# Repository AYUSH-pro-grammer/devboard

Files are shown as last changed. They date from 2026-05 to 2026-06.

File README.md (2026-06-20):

# DevBoard

Custom RP2040-based development board for embedded systems and hardware prototyping.

## Images

### Front
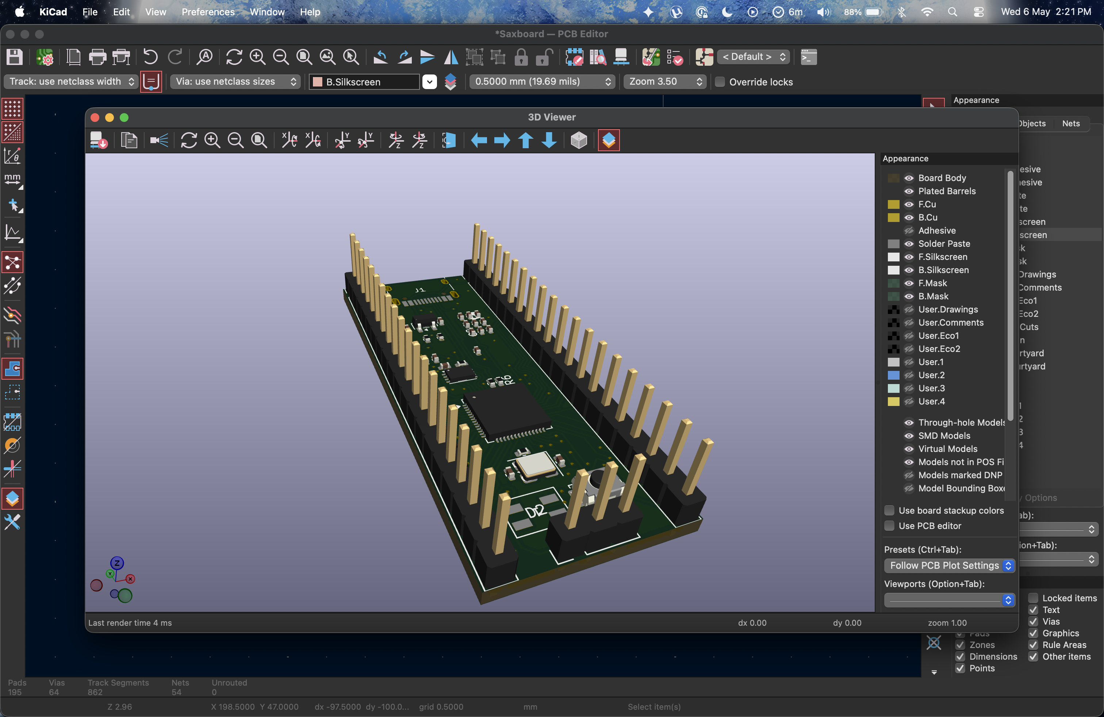
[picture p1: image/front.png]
Front

Screenshot 2026-06-02 at 10 48 57 AM

### Back
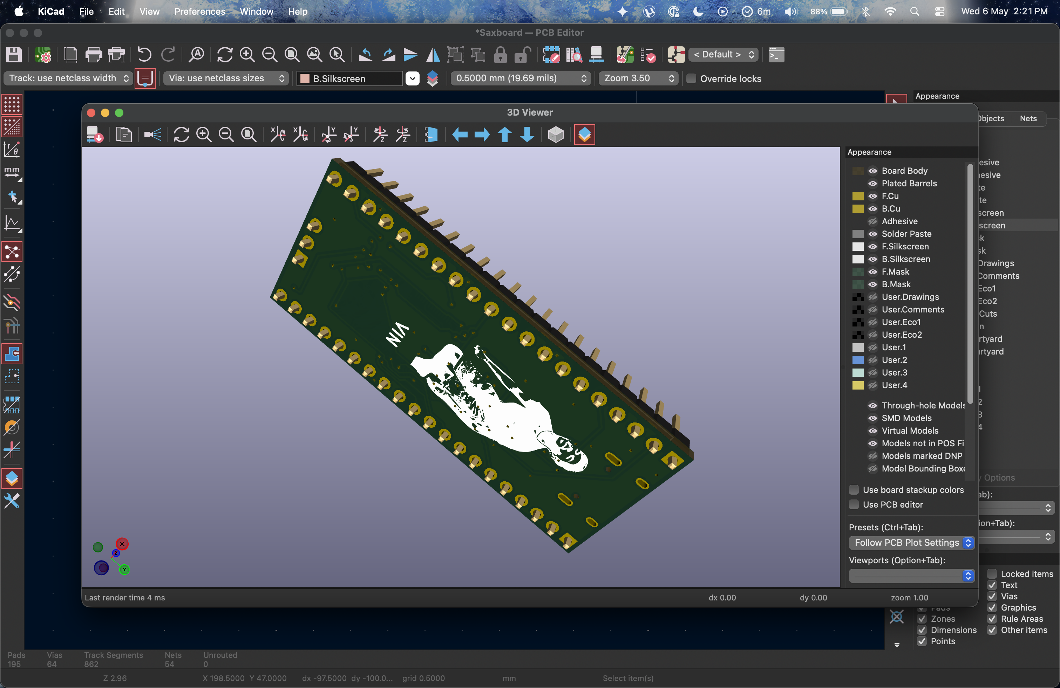
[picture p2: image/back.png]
Back


### PCB
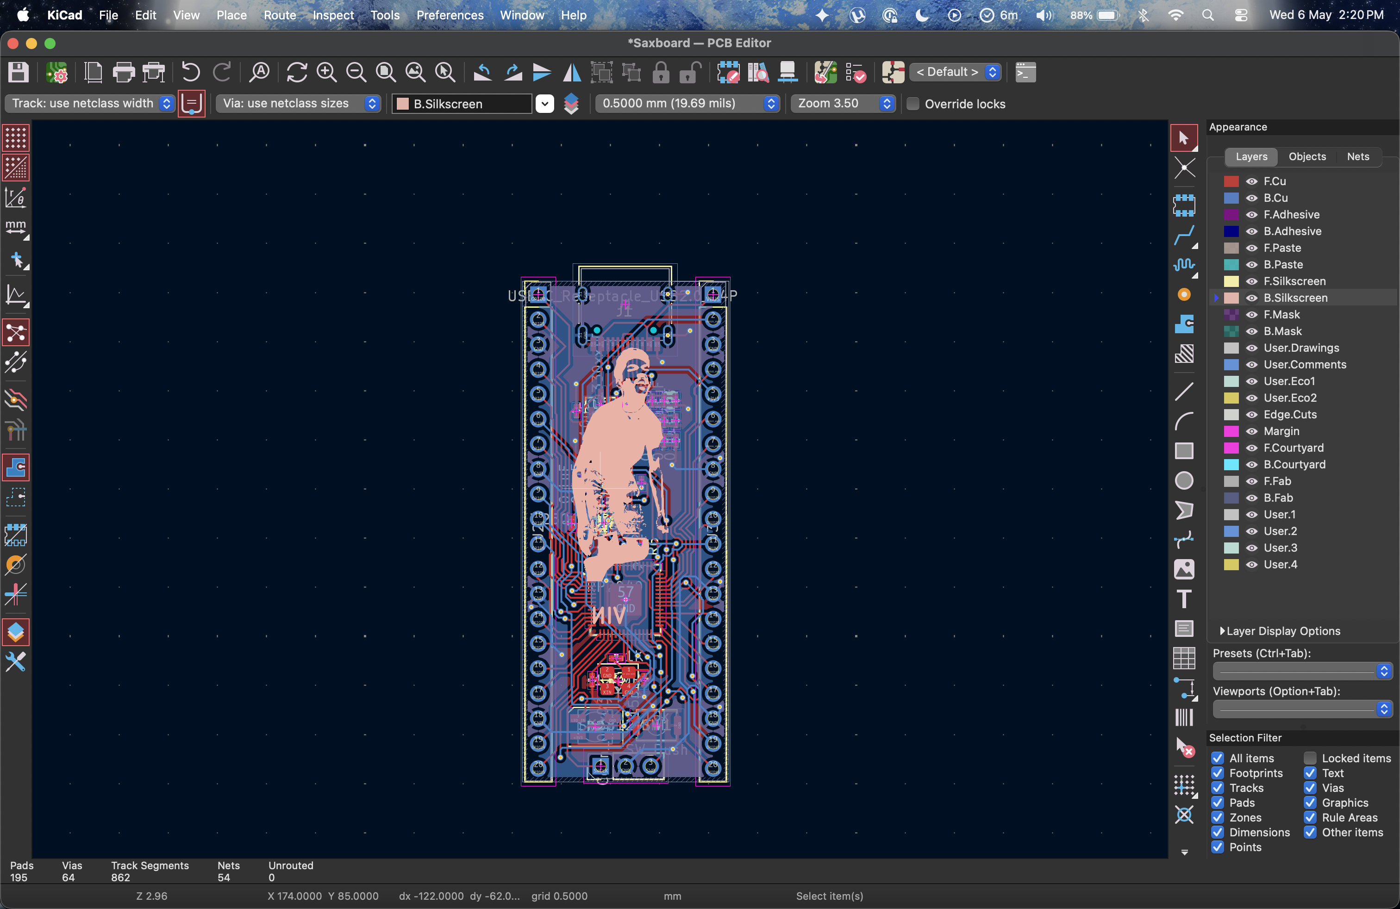
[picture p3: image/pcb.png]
PCB


### Schematic
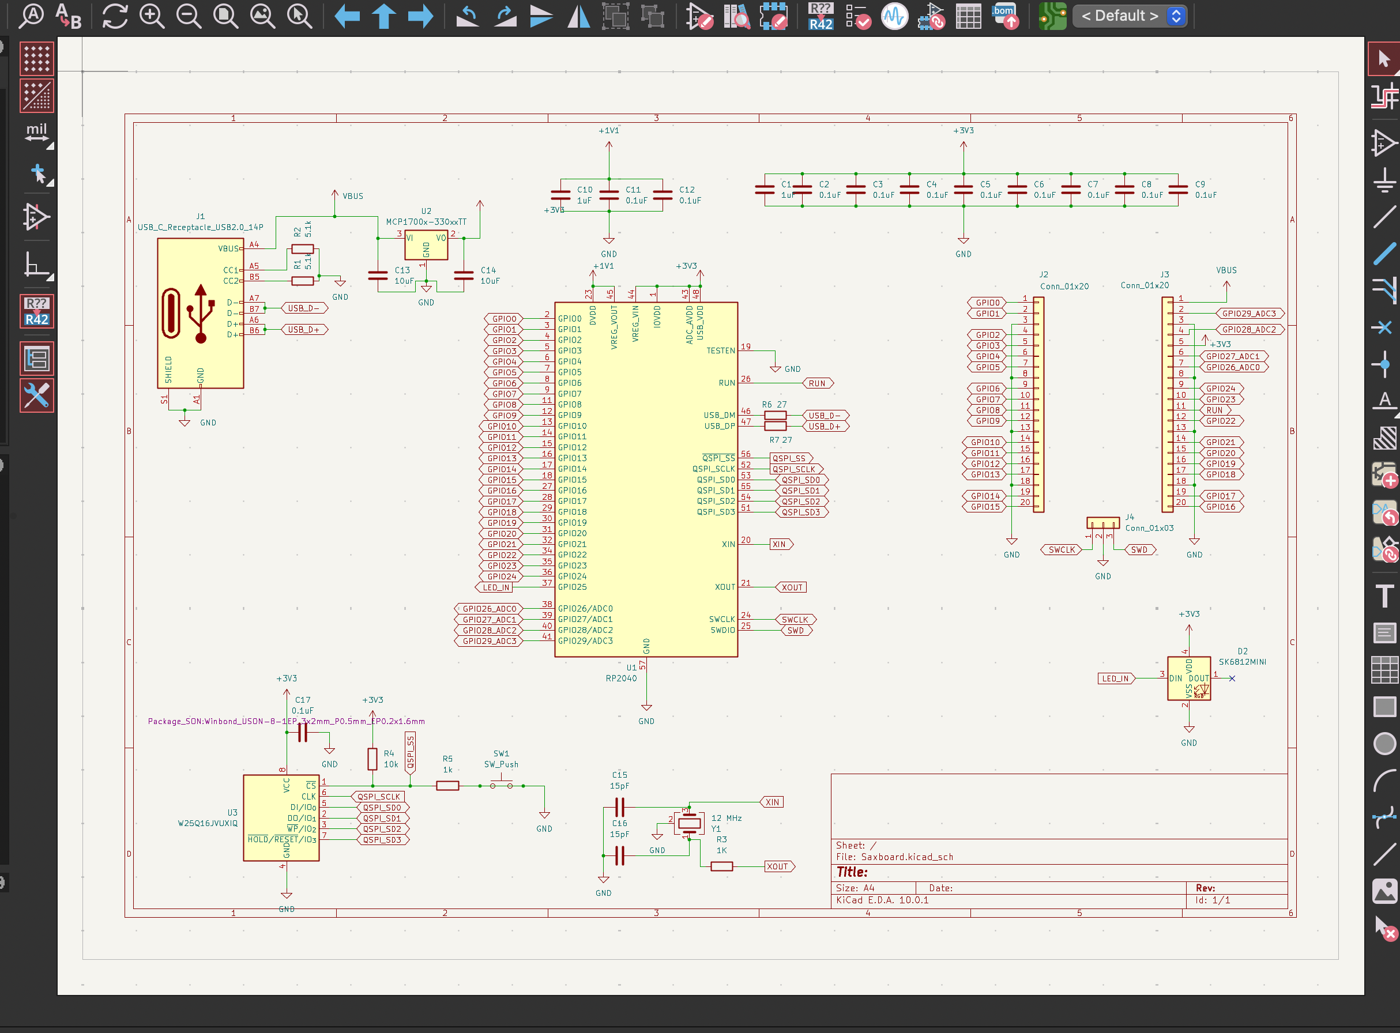
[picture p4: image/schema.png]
Schematic


---

## Bill of Materials (BOM)

The following BOM was used for the RP2040 DevBoard.

| Ref | Qty | Component | LCSC Part # | Manufacturer Part # |
|---|-----:|---|---|---|
| C1, C10 | 2 | 1uF 0402 Capacitor | C52923 | CL05A105KA5NQNC |
| C2-C12, C17 | 11 | 100nF 0402 Capacitor | C1525 | CL05B104KO5NNNC |
| C13, C14 | 2 | 10uF Capacitor | C19702 | CL10A106KP8NNNC |
| C15, C16 | 2 | 15pF 0402 Capacitor | C1548 | 0402CG150J500NT |
| D2 | 1 | SK6812MINI-E RGB LED | C5149201 | SK6812MINI-E |
| J1 | 1 | USB Type-C Connector | C165948 | TYPE-C-31-M-12 |
| R1, R2 | 2 | 5.1kΩ 0402 Resistor | C25905 | 0402WGF5101TCE |
| R3, R5 | 2 | 1kΩ 0402 Resistor | C11702 | 0402WGF1001TCE |
| R4 | 1 | 10kΩ 0402 Resistor | C25744 | 0402WGF1002TCE |
| R6, R7 | 2 | 27Ω 0402 Resistor | C25100 | 0402WGF270JTCE |
| SW1 | 1 | Push Button | C720477 | TS-1088-AR02016 |
| U1 | 1 | RP2040 Microcontroller | C2040 | RP2040 |
| U2 | 1 | MCP1700 3.3V LDO | C39051 | MCP1700T-3302E/TT |
| U3 | 1 | W25Q16JVUXIQ SPI Flash | C2843335 | W25Q16JVUXIQ |
| Y1 | 1 | 12MHz Crystal | C9002 | X322512MSB4SI |

### Notes

- Designed around the Raspberry Pi RP2040 microcontroller.
- Uses a 12MHz external crystal and Winbond SPI flash.
- USB Type-C connector footprint is compatible with HRO TYPE-C-31-M-12.
- All resistors and capacitors use 0402 footprints unless otherwise noted.
- Some LCSC parts may become unavailable over time; equivalent parts with matching value, package, and electrical specifications may be substituted.
- For the latest sourcing information, see [`bom.csv`](bom.csv).

### Estimated Cost

| Item | Approx. Cost (USD) |
|---|---:|
| RP2040 | $1.00 |
| Flash Memory | $2.40 |
| USB-C Connector | $0.19 |
| Crystal | $0.10 |
| LDO Regulator | $0.46 |
| RGB LED | $0.09 |
| Passives + Switch | ~$1.00 |
| **Total Electronics Cost** | **~$5–6 per board** |

> Prices vary depending on supplier stock and order quantity.

Screenshot 2026-06-21 at 12 44 32 AM

## Features

- RP2040 Microcontroller
- USB Support
- GPIO Breakout
- I2C / SPI / UART
- Custom PCB Design

---

## Repository Structure

```text
devboard/
│
├── grb/
├── image/
├── kicad/
├── grb.zip
└── README.md
```

---

## Files

- `grb/` → Gerber manufacturing files
- `image/` → Board images and schematic
- `kicad/` → KiCad design files
- `grb.zip` → Exported Gerber archive

---

## Author

Created by [AYUSH-pro-grammer](https://github.com/AYUSH-pro-grammer)

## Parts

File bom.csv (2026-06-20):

Reference | Qty Per Board | Qty For 2 Boards | Value | Footprint | LCSC Part # | Manufacturer Part # | Manufacturer | Product URL | Notes
C1,C10 | 2 | 4 | 1uF | C_0402_1005Metric | C52923 | CL05A105KA5NQNC | Samsung Electro-Mechanics | https://www.lcsc.com/product-detail/C52923.html | Decoupling
C2,C3,C4,C5,C6,C7,C8,C9,C11,C12,C17 | 11 | 22 | 0.1uF | C_0402_1005Metric | C1525 | CL05B104KO5NNNC | Samsung Electro-Mechanics | https://www.lcsc.com/product-detail/C1525.html | Decoupling
C13,C14 | 2 | 4 | 10uF | C_0402_1005Metric | C19702 | CL10A106KP8NNNC | Samsung Electro-Mechanics | https://www.lcsc.com/product-detail/C19702.html | Verify footprint size
C15,C16 | 2 | 4 | 15pF | C_0402_1005Metric | C1548 | 0402CG150J500NT | FH | https://www.lcsc.com/product-detail/C1548.html | Crystal load caps
D2 | 1 | 2 | SK6812MINI-E | LED_SK6812MINI | C5149201 | SK6812MINI-E | OPSCO | https://www.lcsc.com/product-detail/C5149201.html | RGB LED
J1 | 1 | 2 | USB-C | HRO_TYPE-C-31-M-12 | C165948 | TYPE-C-31-M-12 | Korean Hroparts Elec | https://www.lcsc.com/product-detail/C165948.html | USB Connector
R1,R2 | 2 | 4 | 5.1k | R_0402_1005Metric | C25905 | 0402WGF5101TCE | UNI-ROYAL | https://www.lcsc.com/product-detail/C25905.html | USB-C CC resistors
R3,R5 | 2 | 4 | 1k | R_0402_1005Metric | C11702 | 0402WGF1001TCE | UNI-ROYAL | https://www.lcsc.com/product-detail/C11702.html
R4 | 1 | 2 | 10k | R_0402_1005Metric | C25744 | 0402WGF1002TCE | UNI-ROYAL | https://www.lcsc.com/product-detail/C25744.html
R6,R7 | 2 | 4 | 27 | R_0402_1005Metric | C25100 | 0402WGF270JTCE | UNI-ROYAL | https://www.lcsc.com/product-detail/C25100.html | USB D+/D-
SW1 | 1 | 2 | Push Button | SW_Push_SPST_NO_Alps_SKRK | C720477 | TS-1088-AR02016 | XUNPU | https://www.lcsc.com/product-detail/C720477.html | BOOTSEL/RESET
U1 | 1 | 2 | RP2040 | QFN-56-1EP_7x7mm | C2040 | RP2040 | Raspberry Pi | https://www.lcsc.com/product-detail/C2040.html | MCU
U2 | 1 | 2 | MCP1700T-3302E/TT | SOT-23 | C39051 | MCP1700T-3302E/TT | Microchip | https://www.lcsc.com/product-detail/C39051.html | 3.3V LDO
U3 | 1 | 2 | W25Q16JVUXIQ | USON-8-1EP_3x2mm | C2843335 | W25Q16JVUXIQ | Winbond | https://www.lcsc.com/product-detail/C2843335.html | SPI Flash
Y1 | 1 | 2 | 12MHz | Crystal_3225 | C9002 | X322512MSB4SI | YXC Crystal Oscillators | https://www.lcsc.com/product-detail/C9002.html | System Clock

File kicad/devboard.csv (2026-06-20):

Reference | Qty | Value | DNP | Exclude from BOM | Exclude from Board | Footprint | Datasheet
C1,C10 | 2 | 1uF |  |  |  | Capacitor_SMD:C_0402_1005Metric
C2,C3,C4,C5,C6,C7,C8,C9,C11,C12,C17 | 11 | 0.1uF |  |  |  | Capacitor_SMD:C_0402_1005Metric
C13,C14 | 2 | 10uF |  |  |  | Capacitor_SMD:C_0402_1005Metric
C15,C16 | 2 | 15pF |  |  |  | Capacitor_SMD:C_0402_1005Metric
D2 | 1 | SK6812MINI |  |  |  | LED_SMD:LED_SK6812MINI_PLCC4_3.5x3.5mm_P1.75mm | https://cdn-shop.adafruit.com/product-files/2686/SK6812MINI_REV.01-1-2.pdf
J1 | 1 | USB_C_Receptacle_USB2.0_14P |  |  |  | Connector_USB:USB_C_Receptacle_HRO_TYPE-C-31-M-12 | https://www.usb.org/sites/default/files/documents/usb_type-c.zip
J2,J3 | 2 | Conn_01x20 |  |  |  | Connector_PinHeader_2.54mm:PinHeader_1x20_P2.54mm_Vertical
J4 | 1 | Conn_01x03 |  |  |  | Connector_PinHeader_2.54mm:PinHeader_1x03_P2.54mm_Vertical
R1,R2 | 2 | 5.1k |  |  |  | Resistor_SMD:R_0402_1005Metric
R3 | 1 | 1K |  |  |  | Resistor_SMD:R_0402_1005Metric
R4 | 1 | 10k |  |  |  | Resistor_SMD:R_0402_1005Metric
R5 | 1 | 1k |  |  |  | Resistor_SMD:R_0402_1005Metric
R6,R7 | 2 | 27 |  |  |  | Resistor_SMD:R_0402_1005Metric
SW1 | 1 | SW_Push |  |  |  | Button_Switch_SMD:SW_Push_SPST_NO_Alps_SKRK
U1 | 1 | RP2040 |  |  |  | Package_DFN_QFN:QFN-56-1EP_7x7mm_P0.4mm_EP3.2x3.2mm | https://datasheets.raspberrypi.com/rp2040/rp2040-datasheet.pdf
U2 | 1 | MCP1700x-330xxTT |  |  |  | Package_TO_SOT_SMD:SOT-23 | http://ww1.microchip.com/downloads/en/DeviceDoc/20001826D.pdf
U3 | 1 | W25Q16JVUXIQ |  |  |  | Package_SON:Winbond_USON-8-1EP_3x2mm_P0.5mm_EP0.2x1.6mm | https://www.winbond.com/resource-files/w25q128jv_dtr%20revc%2003272018%20plus.pdf
Y1 | 1 | 12 MHz |  |  |  | Crystal:Crystal_SMD_3225-4Pin_3.2x2.5mm

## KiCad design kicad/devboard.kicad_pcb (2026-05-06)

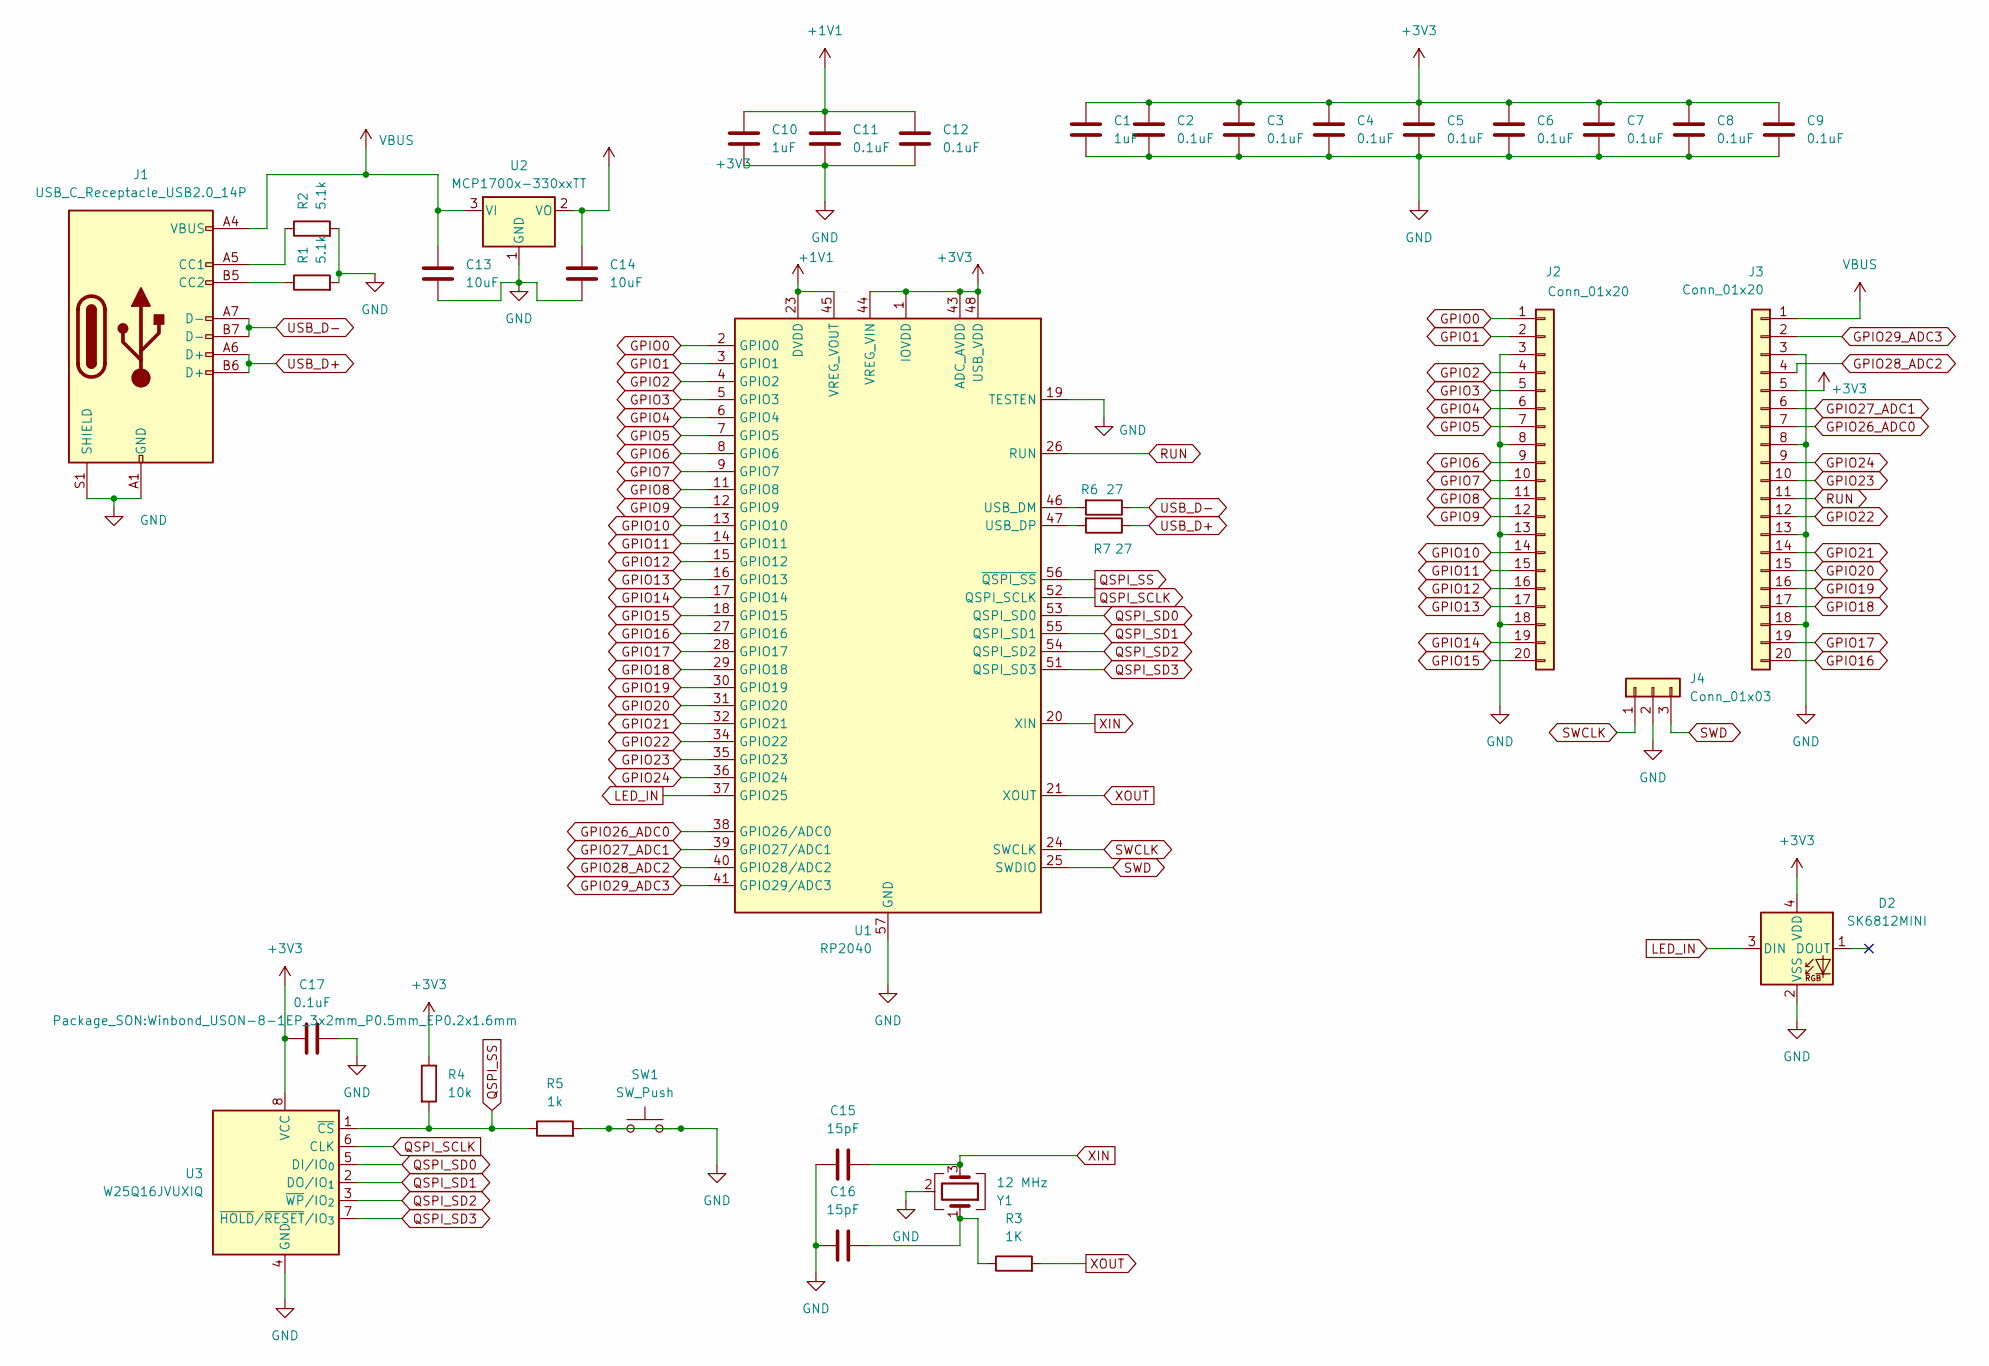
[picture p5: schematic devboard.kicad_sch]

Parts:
C1, C10: 1uF; C_0402_1005Metric
C2, C3, C4, C5, C6, C7, C8, C9, C11, C12, C17: 0.1uF; C_0402_1005Metric
C13, C14: 10uF; C_0402_1005Metric
C15, C16: 15pF; C_0402_1005Metric
D2: SK6812MINI; LED_SK6812MINI_PLCC4_3.5x3.5mm_P1.75mm
J1: USB_C_Receptacle_USB2.0_14P; USB_C_Receptacle_HRO_TYPE-C-31-M-12
J2, J3: Conn_01x20; PinHeader_1x20_P2.54mm_Vertical
J4: Conn_01x03; PinHeader_1x03_P2.54mm_Vertical
R1, R2: 5.1k; R_0402_1005Metric
R3: 1K; R_0402_1005Metric
R4: 10k; R_0402_1005Metric
R5: 1k; R_0402_1005Metric
R6, R7: 27; R_0402_1005Metric
SW1: SW_Push; SW_Push_SPST_NO_Alps_SKRK
U1: RP2040; QFN-56-1EP_7x7mm_P0.4mm_EP3.2x3.2mm
U2: MCP1700x-330xxTT; SOT-23
U3: W25Q16JVUXIQ; Winbond_USON-8-1EP_3x2mm_P0.5mm_EP0.2x1.6mm
Y1: 12 MHz; Crystal_SMD_3225-4Pin_3.2x2.5mm

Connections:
+1V1: C10.1, C11.1, C12.1, U1.23 (DVDD), U1.45 (VREG_VOUT), U1.50 (DVDD)
+3V3: C1.1, C2.1, C3.1, C4.1, C5.1, C6.1, C7.1, C8.1, C9.1, C14.1, C17.1, D2.4 (VDD), J3.5, R4.1, U1.1 (IOVDD), U1.10 (IOVDD), U1.22 (IOVDD), U1.33 (IOVDD), U1.42 (IOVDD), U1.43 (ADC_AVDD), U1.44 (VREG_VIN), U1.48 (USB_VDD), U1.49 (IOVDD), U2.2 (VO), U3.8 (VCC)
GPIO0: J2.1, U1.2 (GPIO0)
GPIO1: J2.2, U1.3 (GPIO1)
GPIO2: J2.4, U1.4 (GPIO2)
GPIO3: J2.5, U1.5 (GPIO3)
GPIO4: J2.6, U1.6 (GPIO4)
GPIO5: J2.7, U1.7 (GPIO5)
GPIO6: J2.9, U1.8 (GPIO6)
GPIO7: J2.10, U1.9 (GPIO7)
GPIO8: J2.11, U1.11 (GPIO8)
GPIO9: J2.12, U1.12 (GPIO9)
GPIO10: J2.14, U1.13 (GPIO10)
GPIO11: J2.15, U1.14 (GPIO11)
GPIO12: J2.16, U1.15 (GPIO12)
GPIO13: J2.17, U1.16 (GPIO13)
GPIO14: J2.19, U1.17 (GPIO14)
GPIO15: J2.20, U1.18 (GPIO15)
GPIO16: J3.20, U1.27 (GPIO16)
GPIO17: J3.19, U1.28 (GPIO17)
GPIO18: J3.17, U1.29 (GPIO18)
GPIO19: J3.16, U1.30 (GPIO19)
GPIO20: J3.15, U1.31 (GPIO20)
GPIO21: J3.14, U1.32 (GPIO21)
GPIO22: J3.12, U1.34 (GPIO22)
GPIO23: J3.10, U1.35 (GPIO23)
GPIO24: J3.9, U1.36 (GPIO24)
GPIO26_ADC0: J3.7, U1.38 (GPIO26/ADC0)
GPIO27_ADC1: J3.6, U1.39 (GPIO27/ADC1)
GPIO28_ADC2: J3.4, U1.40 (GPIO28/ADC2)
GPIO29_ADC3: J3.2, U1.41 (GPIO29/ADC3)
LED_IN: D2.3 (DIN), U1.37 (GPIO25)
unnamed: C16.2, R3.1, Y1.1
unnamed: J1.A5 (CC1), R2.1
unnamed: J1.B5 (CC2), R1.1
unnamed: R6.2, U1.46 (USB_DM)
unnamed: R7.2, U1.47 (USB_DP)
QSPI_SCLK: U1.52 (QSPI_SCLK), U3.6 (CLK)
QSPI_SD0: U1.53 (QSPI_SD0), U3.5 (DI/IO_{0})
QSPI_SD1: U1.55 (QSPI_SD1), U3.2 (DO/IO_{1})
QSPI_SD2: U1.54 (QSPI_SD2), U3.3 (~WP/IO_{2})
QSPI_SD3: U1.51 (QSPI_SD3), U3.7 (~HOLD/~RESET/IO_{3})
QSPI_SS: R4.2, R5.1, U1.56 (~QSPI_SS), U3.1 (~CS)
RUN: J3.11, U1.26 (RUN)
SWCLK: J4.1, U1.24 (SWCLK)
SWD: J4.3, U1.25 (SWDIO)
USB_D+: J1.A6 (D+), J1.B6 (D+), R7.1
USB_D-: J1.A7 (D-), J1.B7 (D-), R6.1
VBUS: C13.1, J1.A4 (VBUS), J1.A9 (VBUS), J1.B4 (VBUS), J1.B9 (VBUS), J3.1, U2.3 (VI)
XIN: C15.2, U1.20 (XIN), Y1.3
XOUT: R3.2, U1.21 (XOUT)

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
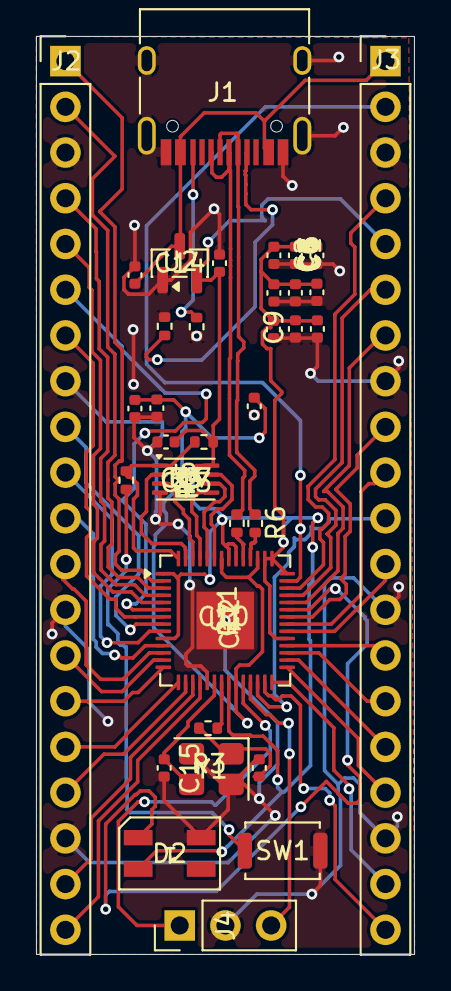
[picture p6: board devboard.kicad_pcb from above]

Board: 2 copper layers, 21.0 x 51.0 mm, 35 parts (1 on the bottom side), 53 nets.

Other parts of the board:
VIN: LOGO; vinmain
